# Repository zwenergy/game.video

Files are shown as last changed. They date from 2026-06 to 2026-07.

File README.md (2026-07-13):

# game.video
A video out adapter for the Tiger game.com handheld.

# This is a work in progress, expect things not being polished and not fully documented!

## General Overview
This project taps in the digital video signals of the Tiger game.com handheld as well as the analog audio (unfortunately, no digital audio is available as the Sharp SM8521 microcontroller has an integrated DAC for audio) and breaks them out to a 10 pin IDC connector.
This connector is placed in the upper cart slot of the handheld to make a complete no-cut mod (note that it only uses the space of the empty cart slot, no connections to the actual cart connector is done here).
A small video out adapter is then connected via an IDC cable which outputs digital video and audio at 720p@60 Hz.

## Hardware Pieces
The project makes use of 3 custom PCBs.
### Video Adapter PCB
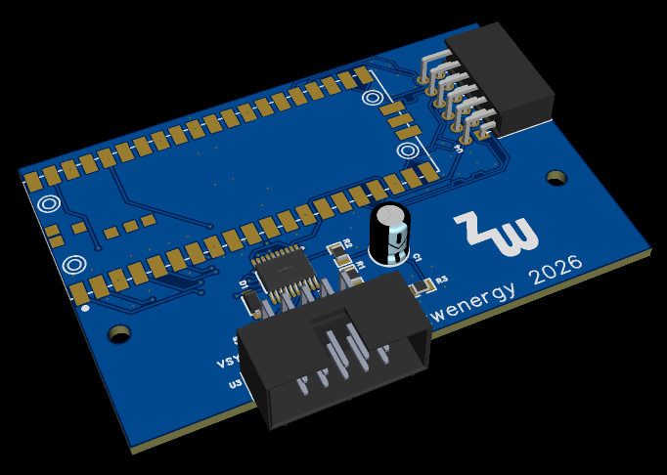
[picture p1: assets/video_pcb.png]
video adapter

This adapter board receives the signals via the 10 pin IDC cable and outputs digital video + audio to the PMOD DVI board.
In order to use the 3D printed shell, the PCB should be ordered with 1.6 mm width.

_**BOM**_

| **Reference** | **Value**| **Links**
|---|---|---|
| U1 | Raspberry Pi Pico 2 (**not** with pre-soldered pin header) ||
| U2 | TI TXB0108PWR |[LCSC](https://www.lcsc.com/product-detail/C53406.html)|
| U3 | 10 pin IDC connector header 90° angle |[LCSC](https://www.lcsc.com/product-detail/C5372873.html)|
| U4 | 2x 6 pin pin 2.54 mm pitch 90° angle female connector ("PMOD") |[LCSC](https://www.lcsc.com/product-detail/C2897426.html)|
| R1, R2 | 100 kOhm resistor (0805) |[LCSC](https://www.lcsc.com/product-detail/C96346.html)|
| R3 | 33 kOhm resistor (0805) |[LCSC](https://www.lcsc.com/product-detail/C17633.html)|
| D1 | Schottky Diode (SOD-123FL) |[LCSC](https://www.lcsc.com/product-detail/C891416.html)|
| C1 | 10 uF capacitor through-hole ||
| | PMOD DVI/HDMI adapter|[AliExpress](https://de.aliexpress.com/item/1005010041828932.html)|

### Flex PCB
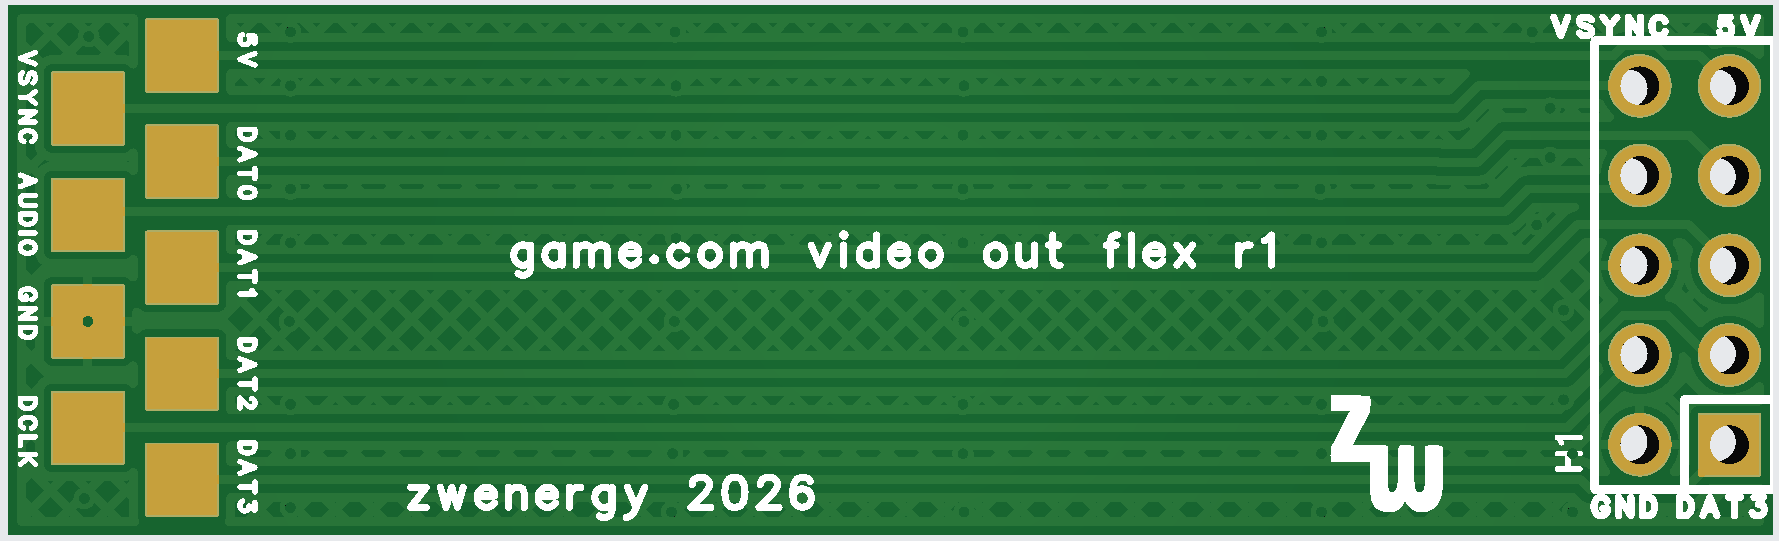
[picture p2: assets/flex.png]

The display and audio signals are soldered via wires to the pads of the flex PCB.
It slides into the cart slot and connects to the IDC connector board.
Make sure to order as a flex PCB.

### Connector PCB
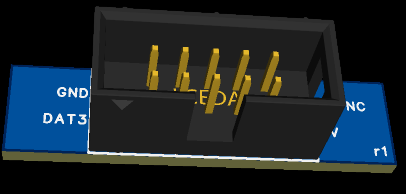
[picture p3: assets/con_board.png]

The connector PCB is soldered to the flex PCB and held in place with a 3D printed bracket.
The PCB should be ordered with 1.6 mm width.

_**BOM**_

| **Reference** | **Value**| **Links**
|---|---|---|
| P1 | 10 pin IDC connector header|[LCSC](https://www.lcsc.com/product-detail/C5665.html)|

## Installation
**WARNING & BEWARE:**
The game.com is a marvellous piece of engineering, so there's a ton of different screws at all kinds of weird places.
Make sure to remember which screw goes where.
Besides, the touch screen connector flex cable is only partially glued down to the motheboard and somewhat given pressure by the display bracket.
That glue has mostly disintegrated 30 years later, so be very careful when handling the display.

**All that to say: Be careful when disassembling a game.com, you can easily break stuff or mix screws up or other bad things.
This thing has a bad production quality in the first place.
<ins>Everything is done at your own risk.</ins>**

**Also, this still is a work-in-progress! Any additional feedback or installation photos/guides are very welcome!**

Prepare the flex cable + connector PCB combo.
For this solder the IDC connector on the PCB and the flex cable on the back of it.
The PCB shows the supposed orientation of the IDC connector (the notch is marked).
Make sure to align the flex cable also in the correct orientation (check the the signal names + positions on the flex line up with the signal names + positions on the connector PCB).

Disassemble the Tiger game.com to the point where you can remove the motherboard from the shell and access the back of the motherboard.
Be careful when opening the shell, as the speaker is stuck to the front part of the shell and hard-wired.
Also be careful when taking out the motherboard from the bottom shell, as the battery contacts are stuck to the bottom and shell and hard-wired to the motherboard.
8 out of the 9 signals to be wired to the flex cable pads are connected to the display signal pin headers.
Wire the signals from the following points to the corresponding pads on the flex cable (try to make the wires as short as possible, but keep in mind where there flex cable is situated so that you can still nicely route the wires when placing back the motherboard into the shell).

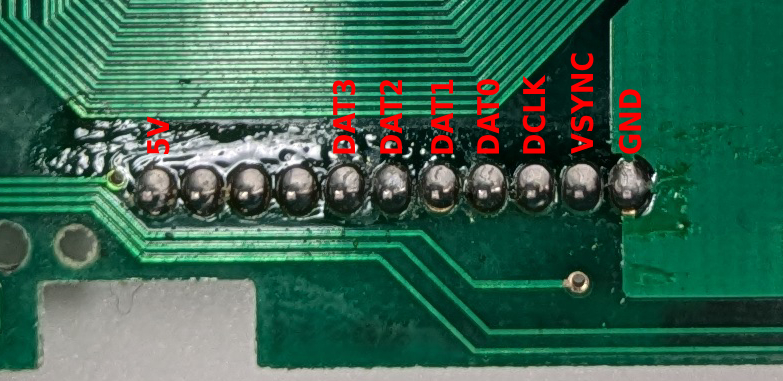
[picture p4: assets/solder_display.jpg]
display solder points


The audio pad on the flex cable has to be wired up to the same solder point of the headphone connector where the **blue** wire of the headphone connector is connected to (_**INSERT A PHOTO HERE**_).
Make sure to keep all the existing flimsy connections for the headphone connector intact.

Wrap the part of the flex cable with the solder pads from both sides with kapton or electrical kape to make sure no short-circuits can happen.
Place the connector PCB into the 3D printed bracket.
Now place the motherboard back into the bottom shell and align the video connector combo into the upper cart slot (**under** the right-hand controller sub-PCB).
Carefully re-insert the "cart slot cover", making sure everything still fits and screw in place.
During the step, the additional flex cable length can be carefully folded in the empty cart slot and/or placed under the controller sub-PCB's ribbon cable.

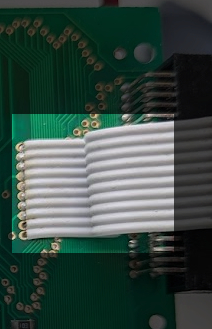
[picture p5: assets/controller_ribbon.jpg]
controller ribbon cable


_**INSERT FURTHER INSTALL STEPS HERE**_

## Disclaimer
**Use the files and/or schematics to build your own board at your own risk**.
This project works fine for me, but it's a simple hobby project, so there is no liability for errors in the schematics and/or board files.
**Use at your own risk**.

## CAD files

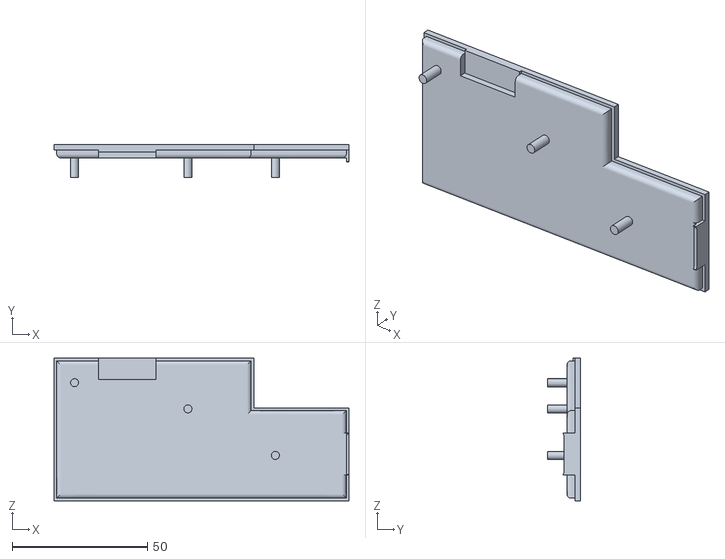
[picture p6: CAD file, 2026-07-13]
STL/game.video main shell top.stl
108.9 x 12.2 x 52.8

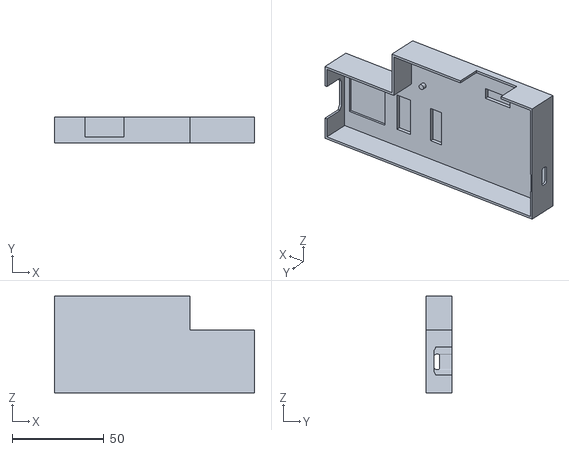
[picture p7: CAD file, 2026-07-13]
STL/game.video main shell bottom.stl
108.9 x 14.0 x 52.8

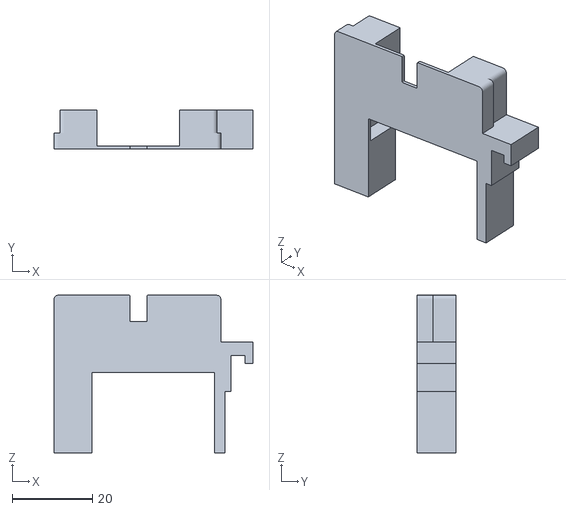
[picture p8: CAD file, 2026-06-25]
STL/game.video connector cart.stl
49.5 x 9.80 x 39.2

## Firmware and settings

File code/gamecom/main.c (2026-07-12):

#include <stdio.h>

#include "pico_hdmi/hstx_data_island_queue.h"
#include "pico_hdmi/hstx_packet.h"
#include "pico_hdmi/video_output.h"

#include "pico/multicore.h"
#include "pico/stdlib.h"

#include "hardware/clocks.h"
#include "hardware/vreg.h"
#include "hardware/structs/bus_ctrl.h"

#include <math.h>
#include <string.h>

// PIOs.
#include "hardware/pio.h"
#include "hardware/dma.h"
#include "hardware/adc.h"
#include "captureVideo.pio.h"
#include "frameStart.pio.h"
#include "frameStartNotifier.pio.h"

#define AUDIO_PIN 26
#define ADC_CHANNEL 0
#define AUDIO_SAMPLES 1024

#ifdef VIDEO_MODE_1280x720
#define FRAME_WIDTH 1280
#define FRAME_HEIGHT 720
#define BOX_SIZE 64
#define SCALE 4
#define SCALE4
#else
#define FRAME_WIDTH 640
#define FRAME_HEIGHT 480
#define BOX_SIZE 32
#define SCALE 2
#endif
//#define BG_COLOR 0x0010  // Dark blue (RGB565)
#define BG_COLOR 0x0000

// GAME.COM Defs.
#define DAT0 0
#define DAT1 1
#define DAT2 2
#define DAT3 3
#define DCLK 4
#define VSYNC 5

#define GAMECOM_WIDTH 200
#define GAMECOM_HEIGHT 160
#define GAMECOM_RAWBUFFER_SIZE ( ( GAMECOM_WIDTH * GAMECOM_HEIGHT ) / 32 )
#define FRAMEBLEND 4

#define VIEWPORT_X ( ( FRAME_WIDTH - ( GAMECOM_WIDTH * SCALE ) ) / 2 )
#define VIEWPORT_Y ( ( FRAME_HEIGHT - ( GAMECOM_HEIGHT * SCALE ) ) / 2 )

#define VSYNC_WAIT_CNT ( ( ( GAMECOM_WIDTH * GAMECOM_HEIGHT ) / 4 ) - 40 )

volatile int audioDMAChanDat;
int audio_frame_counter = 0;

uint16_t audioBuffer[ AUDIO_SAMPLES ] __attribute__((section(".sramdma"))) __attribute__((aligned(2048)));;

unsigned bufferReadCnt __attribute__((section(".sramdma"))) = 0;
unsigned bufferWriteCnt __attribute__((section(".sramdma"))) = 0;
unsigned fullBuffer __attribute__((section(".sramdma"))) = 0;

// Filter.
float previous_sample = 0.0f;
float alpha = 0.5f; // Lower = more muffled/smoother, Higher = more noise/clearer
#define NOISE_GATE (4096/1000)

static void __not_in_flash_func( pushAudioSamples )() {
  bufferWriteCnt =  ( ( dma_hw->ch[ audioDMAChanDat ].write_addr - ( (uint32_t) audioBuffer ) ) / 2 );
  unsigned ptrDist = ( bufferWriteCnt - bufferReadCnt ) % AUDIO_SAMPLES;
  
  // Keep the audio queue fed.
  while ( hstx_di_queue_get_level() < 200 && ptrDist >= 8 ) {
    audio_sample_t samples[ 4 ];
    for ( int i = 0; i < 4; i++ ) {
      // Unsigned 12b sample centered around 2^11     
      int16_t s = audioBuffer[ bufferReadCnt++ ];
      // Filter it.
      float current_sample = (float) s;
      float filtered = ( alpha * current_sample ) + ( ( 1.0f - alpha ) * previous_sample );
    
      // Store for the next iteration
      previous_sample = filtered;
    
      // Cast back to integer
      s = (int16_t) filtered;
      
      if ( bufferReadCnt == AUDIO_SAMPLES ) {
        bufferReadCnt = 0;
      }
      
      // Center
      s = s - ( 1 << 11 );
      
      if ( s < NOISE_GATE && s > -NOISE_GATE ) {
        s = 0;
      }
      
      // Increase volume.
      s = s << 3;
      samples[i].left = s;
      samples[i].right = s;
    }

    // Create audio packet.
    hstx_packet_t packet;
    audio_frame_counter = hstx_packet_set_audio_samples( &packet, samples, 4, audio_frame_counter );

    hstx_data_island_t island;
    hstx_encode_data_island( &island, &packet, false, DI_HSYNC_ACTIVE );
    hstx_di_queue_push( &island );
    
    // Update distance.
    bufferWriteCnt =  ( ( dma_hw->ch[ audioDMAChanDat ].write_addr - ( (uint32_t) audioBuffer ) ) / 2 );
    ptrDist = ( bufferWriteCnt - bufferReadCnt ) % AUDIO_SAMPLES;
  }
  
}

uint32_t rawFB[ GAMECOM_RAWBUFFER_SIZE * 2 ] __attribute__((section(".sramdma")));
PIO notifierPIO;
uint notifierSM;

unsigned int tmpSM;

void __not_in_flash_func( doPIOStuff )() {
  printf( "do pio stuff\n" );
  // Set up PIOs.
  
  // Video capture PIO.
  PIO pio = pio0;
  uint offset_captureVideo = pio_add_program( pio, &captureVideo_program );
  uint sm_captureVideo = pio_claim_unused_sm( pio, true );
  
  // Frame start reset PIO.
  uint sm_frameStart = pio_claim_unused_sm( pio, true );
  uint offset_frameStart = pio_add_program( pio, &frameStart_program );
  tmpSM = sm_frameStart;
  
  // Frame start notifier.
  uint sm_frameStartNotifier = pio_claim_unused_sm( pio, true );
  uint offset_frameStartNotifier = pio_add_program( pio, &frameStartNotifier_program );
  notifierPIO = pio;
  notifierSM = sm_frameStartNotifier;
  
  printf( "Created pios\n" );

  
  // DMA to copy pixels to FB.
  int fbFill_dma = 3;
  
  dma_channel_config c = dma_channel_get_default_config( fbFill_dma );
  channel_config_set_transfer_data_size( &c, DMA_SIZE_32 );
  channel_config_set_read_increment( &c, false );
  channel_config_set_write_increment( &c, true );
  channel_config_set_dreq( &c, pio_get_dreq( pio, sm_captureVideo, false) );

  dma_channel_configure(
    fbFill_dma,
    &c,
    rawFB, // Write to FB.
    &pio->rxf[ sm_captureVideo ],  // Read from captureVideo RX FIFO
    dma_encode_endless_transfer_count(),        // run inf.
    false                                       // Don't start yet
  );
  
  // DMA to reset fbFill DMA.
  int fbReset_dma = 4;
  c = dma_channel_get_default_config( fbReset_dma );
  channel_config_set_transfer_data_size( &c, DMA_SIZE_32 );
  channel_config_set_read_increment( &c, false );
  channel_config_set_write_increment( &c, false );
  channel_config_set_dreq( &c, pio_get_dreq( pio, sm_frameStart, false) );

  dma_channel_configure(
    fbReset_dma,
    &c,
    &dma_hw->ch[ fbFill_dma ].write_addr, // Write to fbFill DMA's write address.
    &pio->rxf[ sm_frameStart ],  // Read from frameStart RX FIFO
    dma_encode_endless_transfer_count(),        // run inf.
    false                                       // Don't start yet
  );
  
  printf( "Created DMAs\n" );
  
  // Start the DMAs.
  dma_start_channel_mask( 1u << fbFill_dma );
  dma_start_channel_mask( 1u << fbReset_dma );
  
  // Start the SMs.
  frameStart_program_init( pio, sm_frameStart, offset_frameStart );
  frameStartNotifier_program_init( pio, sm_frameStartNotifier, offset_frameStartNotifier );

  // Put the FB addr.
  pio_sm_put( pio, sm_frameStart, (uint32_t) rawFB );
  
  // Put the wait pixels.
  pio_sm_put( pio, sm_frameStart, VSYNC_WAIT_CNT );
  pio_sm_put( pio, sm_frameStartNotifier, VSYNC_WAIT_CNT );
  
  captureVideo_program_init( pio, sm_captureVideo, offset_captureVideo, DAT0 );
}

uint32_t __not_in_flash_func( expandTo16bPixel )( uint32_t pxl ) {
  uint32_t c;
  
  if ( pxl == 0b00000100 ) {
    c = 0b1111111111111111;
  } else if ( pxl >= 0b00000010 ) {
    if ( pxl == 0b00000010 ) {
      c = 0b1000010000010000;
    } else {
      c = 0b1011110111110111;
    }
  } else {
    if ( pxl == 0b00000001 ) {
      c = 0b0100001000001000;
    } else {
      c = 0b0000000000000000;
    }
  }
  
  return c;
}

uint32_t __not_in_flash_func( expandAndCombine )( uint32_t pxl0, uint32_t pxl1 ) {
  return ( ( ( expandTo16bPixel( pxl1 )  ) << 16 ) | expandTo16bPixel( pxl0 ) );  
};

uint32_t localRawFB[ GAMECOM_RAWBUFFER_SIZE * FRAMEBLEND ];
uint32_t curFB[ GAMECOM_HEIGHT * GAMECOM_WIDTH ];
#ifdef SCALE4
uint32_t expanded16bFB[ ( GAMECOM_HEIGHT * GAMECOM_WIDTH * 2 ) / 2 ];
#else
uint32_t expanded16bFB[ ( GAMECOM_HEIGHT * GAMECOM_WIDTH * SCALE ) / 2 ];
#endif

unsigned frameCnt = 0;
void __not_in_flash_func( processCapture )() {
  
  // Wait until a new frame was captured.
  if ( pio_sm_is_rx_fifo_empty( notifierPIO, notifierSM ) ) {
    return;
  }
  
  // Copy the data.
  memcpy( localRawFB + (GAMECOM_RAWBUFFER_SIZE * frameCnt), rawFB, 
    GAMECOM_RAWBUFFER_SIZE * 4 );
    
  // Get the dummy to empty the FIFO.    
  pio_sm_get( notifierPIO, notifierSM );
  
  if ( frameCnt == ( FRAMEBLEND - 1 ) ) {
    frameCnt = 0;
  } else {
    ++frameCnt;
  }
  
  // Do the actual processing to create the current frame buffer.
  for ( unsigned blendCnt = 0; blendCnt < FRAMEBLEND; ++blendCnt ) {
    unsigned curX = 0;
    unsigned curY = 0;
    unsigned rotCnt = 0;
    for ( unsigned sampleCnt = 0; sampleCnt < GAMECOM_RAWBUFFER_SIZE; ++sampleCnt ) {      
      // Get the current sample.
      uint32_t curSample = ~( localRawFB[ sampleCnt + ( blendCnt * GAMECOM_RAWBUFFER_SIZE ) ] );
      // Each sample contains 32 pixels, grouped in 4 lines. Go through them.
      for ( unsigned groupCnt = 0; groupCnt < 8; ++groupCnt ) {
        
        uint32_t curGroup = ( curSample >> ( groupCnt * 4 ) );
        uint32_t dat0 = ( curGroup & 0b000001 ) >> 0;
        uint32_t dat1 = ( curGroup & 0b000010 ) >> 1;
        uint32_t dat2 = ( curGroup & 0b000100 ) >> 2;
        uint32_t dat3 = ( curGroup & 0b001000 ) >> 3;
        
        if ( blendCnt == 0 ) {
          curFB[ curX + ( ( curY + 0 ) * GAMECOM_WIDTH ) ] = dat0;
          curFB[ curX + ( ( curY + 1 ) * GAMECOM_WIDTH ) ] = dat1;
          curFB[ curX + ( ( curY + 2 ) * GAMECOM_WIDTH ) ] = dat2;
          curFB[ curX + ( ( curY + 3 ) * GAMECOM_WIDTH ) ] = dat3;
        } else {
          curFB[ curX + ( ( curY + 0 ) * GAMECOM_WIDTH ) ] += dat0;
          curFB[ curX + ( ( curY + 1 ) * GAMECOM_WIDTH ) ] += dat1;
          curFB[ curX + ( ( curY + 2 ) * GAMECOM_WIDTH ) ] += dat2;
          curFB[ curX + ( ( curY + 3 ) * GAMECOM_WIDTH ) ] += dat3;
        }
        
        if ( rotCnt < 39 ) {
          rotCnt += 1;
          curY += 4;
        } else {
          rotCnt = 0;
          curY = 0;
          curX += 1;
        }
      }
    }
  }
  
  
  // Expand values to RGB 565.
  if ( SCALE == 1 ) {
    for ( unsigned y = 0; y < GAMECOM_HEIGHT; ++y ) {
      for ( unsigned x = 0; x < GAMECOM_WIDTH; x += 2  ) {
        expanded16bFB[ ( x / 2 ) + ( y * ( GAMECOM_WIDTH / 2 ) ) ] = 
          expandAndCombine( curFB[ x + ( y * GAMECOM_WIDTH ) ], 
                            curFB[ x + 1 + ( y * GAMECOM_WIDTH ) ] );
      }
    }
  } else if ( SCALE == 2 ) {
    // SCALE = 2
    for ( unsigned y = 0; y < GAMECOM_HEIGHT; ++y ) {
      for ( unsigned x = 0; x < GAMECOM_WIDTH; x += 1  ) {
        uint32_t curPxl = curFB[ x + ( y * GAMECOM_WIDTH ) ];
        expanded16bFB[ ( x + ( y * ( GAMECOM_WIDTH ) ) ) ] = 
          expandAndCombine( curPxl, curPxl );
      }
    }
  } else if ( SCALE == 4 ) {
    
    unsigned expCnt = 0;
    for ( unsigned y = 0; y < GAMECOM_HEIGHT; ++y ) {
      // Also do some audio stuff in beetween.
      for ( unsigned x = 0; x < GAMECOM_WIDTH; x += 1  ) {
        uint32_t curPxl = curFB[ x + ( y * GAMECOM_WIDTH ) ];
        
        expanded16bFB[ expCnt++ ] = 
          expandAndCombine( curPxl, curPxl );
      }
    }
  }
}

// ============================================================================
// Scanline Callback (runs on Core 1)
// ============================================================================

static void __scratch_x("") scanline_callback(uint32_t v_scanline, uint32_t active_line, uint32_t *dst)
{
  (void) v_scanline;

  int fb_line = active_line;

  uint32_t bg = BG_COLOR | (BG_COLOR << 16);
      
  // Viewport lines?
  if ( fb_line >= VIEWPORT_Y && fb_line < ( VIEWPORT_Y + ( GAMECOM_HEIGHT * SCALE ) ) ) {
    int i = 0;
    // Region 1: before viewport
    // Note: iterating by 2 pixels at a time (1 uint32_t)
    for (; i < ( VIEWPORT_X / 2 ); i++) {
        dst[i] = bg;
    }
    
    // Region 2: viewport
    #ifdef SCALE4
    const uint32_t w = ( GAMECOM_WIDTH / 2 ) * 2;
    int n = ( ( fb_line - VIEWPORT_Y ) / SCALE ) * ( w );
    // Note: iterating by 2 pixels at a time (1 uint32_t)
    for (; i < ( VIEWPORT_X / 2 ) + (w*2); i++) {
        dst[i++] = expanded16bFB[ n ];
        dst[i] = expanded16bFB[ n++ ];
    }
    #else
    const uint32_t w = ( GAMECOM_WIDTH / 2 ) * SCALE;
    int n = ( ( fb_line - VIEWPORT_Y ) / SCALE ) * ( w );
    // Note: iterating by 2 pixels at a time (1 uint32_t)
    for (; i < ( VIEWPORT_X / 2 ) + w; i++) {
        dst[i] = expanded16bFB[ n++ ];
    }
    #endif
    
    // Region 3: after viewport.
    for (; i < FRAME_WIDTH / 2; i++) {
          dst[i] = bg;
      }
    
  } else {
    // Background.
    for (int i = 0; i < FRAME_WIDTH / 2; i++) {
      dst[i] = bg;
    }
  }
}

void __not_in_flash_func( videoStuff )() {
  while ( 1 ) {
    // check for game.com frames.
    processCapture();
    // Do audio.
    pushAudioSamples();
  }
}
  

volatile uint32_t audioBufferAddr = (uint32_t) audioBuffer;
int main(void)
{ 
#ifdef VIDEO_MODE_1280x720
    // 720p60: 372 MHz at 1.3V. Closest achievable to 371.25 MHz with 12 MHz XOSC
    // (0.2% high -> 74.4 MHz pixel clock, within HDMI tolerance for 720p60).
    vreg_set_voltage(VREG_VOLTAGE_1_30);
    sleep_ms(10);
    set_sys_clock_khz(372000, true);
#else
    sleep_ms(2);
    vreg_set_voltage(VREG_VOLTAGE_1_30);
    sleep_ms(2);
    set_sys_clock_khz(126000 * 2, true);
#endif
    
    sleep_ms(10);
    stdio_init_all();

    // Initialize LED.
    gpio_init(PICO_DEFAULT_LED_PIN);
    gpio_set_dir(PICO_DEFAULT_LED_PIN, GPIO_OUT);
    
    // Init audio ADC.
    adc_init();
    adc_gpio_init( AUDIO_PIN );
    adc_select_input( ADC_CHANNEL );

    
    adc_fifo_setup(
      true,    // Write each completed conversion to the FIFO
      true,    // Enable DMA data request (DREQ)
      1,       // IREQ asserted when at least 1 samples is present
      false,   // We don't need the error bit
      false    // Keep samples at 12-bit resolution
    );

    adc_set_clkdiv( 999.0f ); // Aiming for ~48kHz
    
    
    
    
    // Audio DMA
    audioDMAChanDat = 13;
    
    dma_channel_config cfg = dma_channel_get_default_config( audioDMAChanDat );
    channel_config_set_high_priority( &cfg, false);
    channel_config_set_transfer_data_size( &cfg, DMA_SIZE_16 );
    channel_config_set_read_increment( &cfg, false );
    channel_config_set_write_increment( &cfg, true );
    channel_config_set_dreq( &cfg, DREQ_ADC );
    channel_config_set_ring( &cfg, true, 11 );

    dma_channel_configure(
      audioDMAChanDat,
      &cfg,
      audioBuffer,
      &adc_hw->fifo,
      dma_encode_endless_transfer_count(),
      false
    );

    // Initialize HDMI output
    hstx_di_queue_init();
    video_output_init( FRAME_WIDTH, FRAME_HEIGHT );
    
    // Init game.com PIOs.
    doPIOStuff();

    // Register scanline callback
    video_output_set_scanline_callback( scanline_callback );

    // Launch Core 1 for HSTX output
    multicore_launch_core1( video_output_core1_run );
    sleep_ms( 100 );
    
    // Set the DMA write priority higher, so the writes to the HSTX over
    // the APB bridge will be prioritized.
    bus_ctrl_hw->priority = BUSCTRL_BUS_PRIORITY_DMA_W_BITS;
    
    dma_channel_start( audioDMAChanDat );
    
    // Start the ADC.
    adc_run( true );
    
    videoStuff();

    return 0;
}

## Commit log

2026-06-25 Add STL.
    [game.video connector cart.stl]
2026-07-12 Added PCBs.
2026-07-13 Add shell files.
    [game.video main shell bottom.stl, game.video main shell top.stl]
